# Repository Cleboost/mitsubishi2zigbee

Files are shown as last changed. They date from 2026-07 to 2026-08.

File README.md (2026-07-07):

# mitsubishi2zigbee

> [!CAUTION]
> **Early development — prototype only. Not production-ready.**
>
> This project is experimental and under active development. Firmware, wiring, and Zigbee behavior may change without notice. Bugs, incomplete features, and unexpected HVAC behavior are possible.
>
> **Do not rely on this device for critical climate control.** Use at your own risk. Test thoroughly before leaving it unattended.

Zigbee gateway firmware for Mitsubishi heat pumps and air conditioners with a **CN105** service port.

An **ESP32-C6** talks to the indoor unit over UART (CN105 protocol) and exposes it as a native Zigbee HVAC thermostat — no Wi-Fi or MQTT bridge on the microcontroller.

```
Home Assistant / Zigbee coordinator  ── Zigbee ──►  ESP32-C6  ── UART ──►  Mitsubishi unit
```

Inspired by [gysmo38/mitsubishi2MQTT](https://github.com/gysmo38/mitsubishi2MQTT), but uses Zigbee clusters (`hvacThermostat` + `hvacFanCtrl`) instead of MQTT.

## Features

| Category | Details |
| --- | --- |
| **Modes** | Off, Heat, Cool, Auto, Fan only, Dry |
| **Setpoint** | 16–31 °C in 0.5 °C steps |
| **Fan speed** | Auto, Quiet (Smart), Low, Medium, High |
| **Vane** | Auto, positions 1–5, Swing |
| **Telemetry** | Room temperature (unit sensor), compressor running state |
| **Status LED** (WS2812) | Fast blue — scanning · Slow blue — network found, not paired · Green pulse — paired |

## Hardware

### Supported board

- [Waveshare ESP32-C6-Zero](https://www.waveshare.com/esp32-c6-zero.htm) (or any ESP32-C6 dev board with similar pinout)
- Built with **ESP-IDF** via **PlatformIO**

### CN105 wiring

The CN105 port provides 12 V, 5 V, and 5 V logic UART lines.

| CN105 pin | Signal | ESP32-C6 | Notes |
| --- | --- | --- | --- |
| 1 | 12 V | — | Do **not** use to power the ESP |
| 2 | GND | GND | Common ground |
| 3 | 5 V | 5 V / VBUS | Powers the ESP32-C6 |
| 4 | TX (unit) | GPIO 5 (RX) | 5 V logic — use a level shifter (5 V → 3.3 V) |
| 5 | RX (unit) | GPIO 4 (TX) | 3.3 V from the ESP is sufficient |

> **Warning:** Never feed 12 V into the ESP. Power the board from the CN105 5 V pin only.

## Build and flash

### Prerequisites

- [PlatformIO](https://platformio.org/) (VS Code extension or CLI)

### Commands

```bash
cd firmware
pio run --target upload    # build and flash
pio device monitor         # serial logs (115200 baud)
```

## Zigbee pairing

1. Flash the firmware and power the board from the CN105 port.
2. Put your Zigbee coordinator into pairing mode.
3. Watch the status LED:
   - Fast blue — searching for a network
   - Slow blue — network found, waiting to join
   - Green pulse — joined successfully
4. The device advertises as **`MZ-Zigbee-C6`** (vendor: Mitsubishi).

## Zigbee2MQTT integration

> **To write** — step-by-step setup guide coming soon.

A video tutorial will cover the full Zigbee2MQTT setup (external converter, `configuration.yaml`, pairing, and Home Assistant entities). Stay tuned.

In the meantime, the external converter source is already available in [`zigbee2mqtt_converter/mitsubishi_esp32c6.js`](zigbee2mqtt_converter/mitsubishi_esp32c6.js).

## Project layout

```
mitsubishi2zigbee/
├── hardware/                  # KiCad PCB (CN105 carrier for ESP32-C6-Zero)
├── firmware/                  # ESP-IDF / PlatformIO project
│   └── src/
│       ├── main.cpp           # Zigbee endpoint + status LED
│       └── cn105.cpp          # Mitsubishi CN105 UART driver
└── zigbee2mqtt_converter/     # Optional Z2M external converter

```

## License

See repository license file.

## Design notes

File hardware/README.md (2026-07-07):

# Hardware

KiCad PCB for a [Waveshare ESP32-C6-Zero](https://www.waveshare.com/esp32-c6-zero.htm) carrier that plugs into a Mitsubishi **CN105** service port.

| Item | Details |
| --- | --- |
| MCU footprint | `Waveshare-ESP32:Waveshare-ESP32-C6-Zero_THT` (2×9 pin headers) |
| CN105 connector | `JST:JST_PA_B05B-PASK-1_1x05_P2.00mm_Vertical_CN105` |
| Level shifting | 5 V UART from the unit → 3.3 V for the ESP |

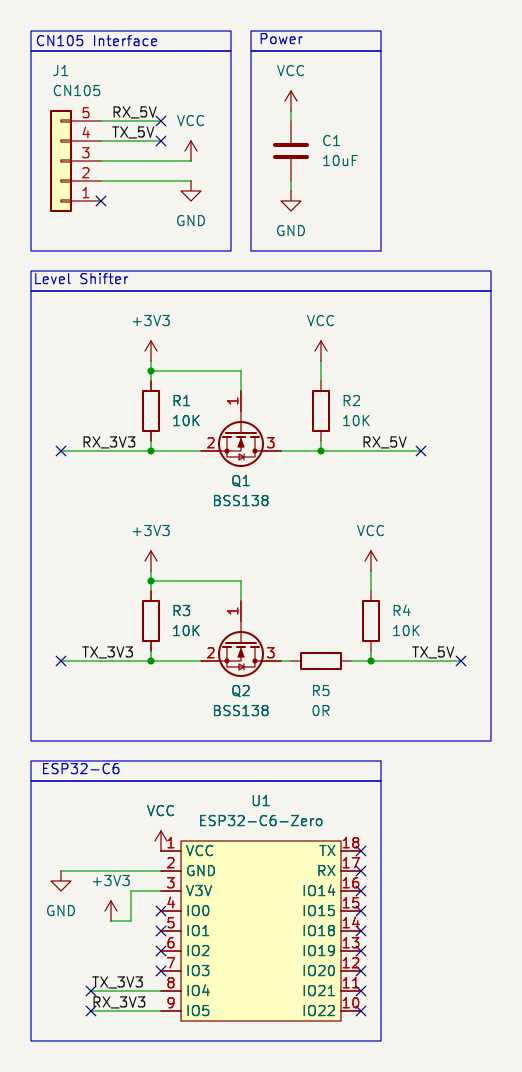
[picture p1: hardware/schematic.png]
Schematic


## Open in KiCad

```bash
kicad hardware/mitsubishi2zigbee.kicad_pro
```

Project-specific symbol and footprint libraries live in `libs/`.

## Layout

```
hardware/
├── README.md
├── schematic.png
├── mitsubishi2zigbee.kicad_pro
├── mitsubishi2zigbee.kicad_sch
├── mitsubishi2zigbee.kicad_pcb
├── fp-lib-table
├── sym-lib-table
└── libs/
    ├── JST.pretty/
    ├── Waveshare-ESP32.pretty/
    └── Waveshare-ESP32.kicad_sym
```

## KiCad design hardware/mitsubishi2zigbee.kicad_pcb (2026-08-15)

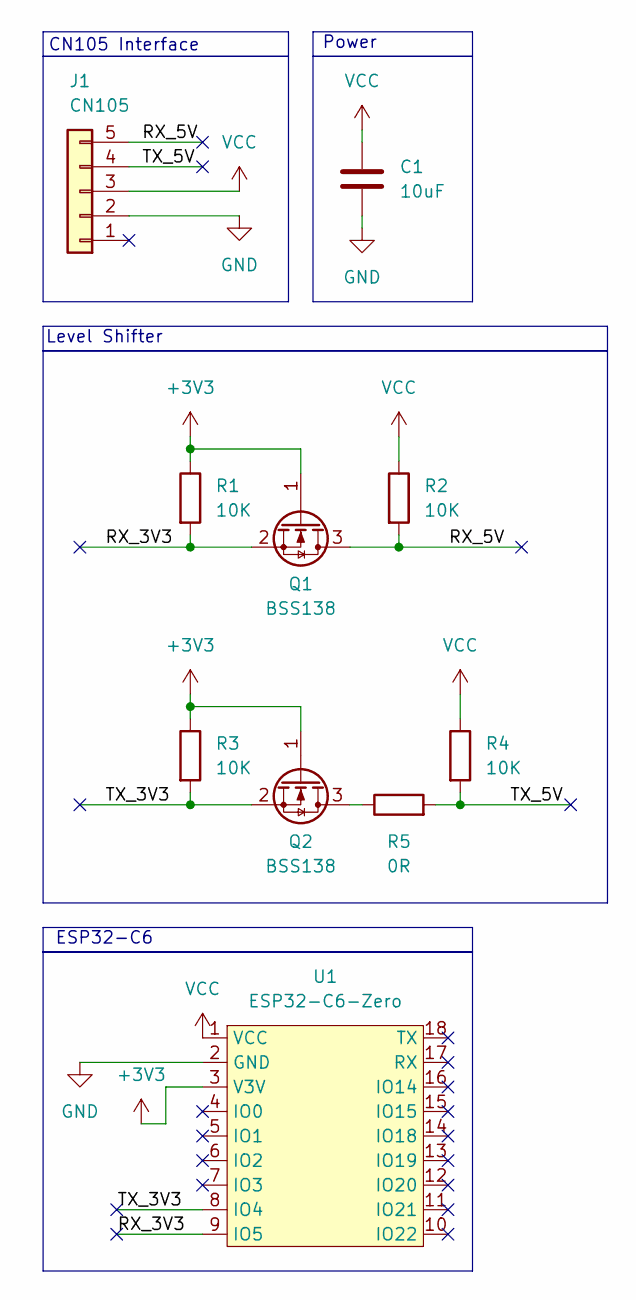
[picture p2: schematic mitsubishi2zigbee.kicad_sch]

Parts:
C1: 10uF; C_0805_2012Metric_Pad1.18x1.45mm_HandSolder
J1: CN105; JST_PA_B05B-PASK-1_1x05_P2.00mm_Vertical_CN105
Q1, Q2: BSS138; SOT-23
R1, R2, R3, R4: 10K; R_0805_2012Metric_Pad1.20x1.40mm_HandSolder
R5: 0R; R_1206_3216Metric_Pad1.30x1.75mm_HandSolder
U1: ESP32-C6-Zero; Waveshare-ESP32-C6-Zero_THT

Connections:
+3V3: Q1.1 (G), Q2.1 (G), R1.1, R3.1, U1.3 (V3V)
/RX_3V3: Q1.2 (S), R1.2, U1.9 (IO5)
/RX_5V: J1.5, Q1.3 (D), R2.2
/TX_3V3: Q2.2 (S), R3.2, U1.8 (IO4)
/TX_5V: J1.4, R4.2, R5.2
GND: C1.1, J1.2, U1.2 (GND)
unnamed: Q2.3 (D), R5.1
VCC: C1.2, J1.3, R2.1, R4.1, U1.1 (VCC)

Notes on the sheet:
CN105 Interface
Level Shifter
ESP32-C6
Power

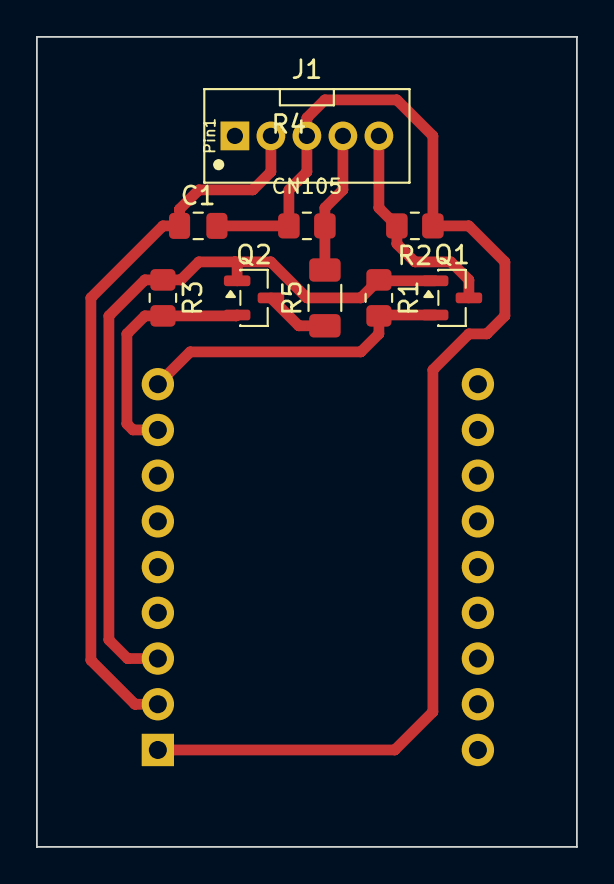
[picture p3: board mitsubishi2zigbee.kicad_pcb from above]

Board: 2 copper layers, 30.0 x 45.0 mm, 10 parts (1 on the bottom side), 8 nets.

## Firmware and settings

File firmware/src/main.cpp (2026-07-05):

// mitsubishi2zigbee — Zigbee gateway for Mitsubishi heat pumps (CN105)
//
// Based on gysmo38/mitsubishi2MQTT; exposes Thermostat + Fan Control clusters
// on ESP32-C6 (ESP-IDF) instead of MQTT.
//
//   Home Assistant ──Zigbee──► ESP32-C6 ──UART CN105──► Mitsubishi unit
//
// Status LED (WS2812, GPIO8): fast blue = scanning | slow blue = found, not paired | green = paired
#include "freertos/FreeRTOS.h"
#include "freertos/task.h"
#include "esp_check.h"
#include "esp_log.h"
#include "nvs_flash.h"
#include "led_strip.h"
#include "esp_zigbee_core.h"
#include "ha/esp_zigbee_ha_standard.h"
#include "bdb/esp_zigbee_bdb_commissioning.h"

#include "cn105.h"
#include "ota_zigbee.h"

static const char *TAG = "MITSU_ZB";

#define LED_PIN     8
#define LED_BRIGHT  20

typedef enum {
    LED_SEARCHING,
    LED_FOUND,
    LED_CONNECTED,
} led_state_t;

static volatile led_state_t g_led_state = LED_SEARCHING;
static led_strip_handle_t   g_led;

static void led_set(uint8_t r, uint8_t g, uint8_t b)
{
    led_strip_set_pixel(g_led, 0, r, g, b);
    led_strip_refresh(g_led);
}
static void led_off(void) { led_strip_clear(g_led); }

static void led_task(void *arg)
{
    led_strip_config_t strip_cfg = {};
    strip_cfg.strip_gpio_num = LED_PIN;
    strip_cfg.max_leds = 1;
    strip_cfg.led_model = LED_MODEL_WS2812;
    strip_cfg.color_component_format = LED_STRIP_COLOR_COMPONENT_FMT_RGB;

    led_strip_rmt_config_t rmt_cfg = {};
    rmt_cfg.resolution_hz = 10 * 1000 * 1000;
    ESP_ERROR_CHECK(led_strip_new_rmt_device(&strip_cfg, &rmt_cfg, &g_led));

    led_set(LED_BRIGHT, LED_BRIGHT, LED_BRIGHT);
    vTaskDelay(pdMS_TO_TICKS(1000));
    led_off();

    while (true) {
        switch (g_led_state) {
        case LED_SEARCHING:
            led_set(0, 0, LED_BRIGHT); vTaskDelay(pdMS_TO_TICKS(150));
            led_off();                 vTaskDelay(pdMS_TO_TICKS(150));
            break;
        case LED_FOUND:
            led_set(0, 0, LED_BRIGHT); vTaskDelay(pdMS_TO_TICKS(800));
            led_off();                 vTaskDelay(pdMS_TO_TICKS(800));
            break;
        case LED_CONNECTED:
            led_set(0, LED_BRIGHT, 0); vTaskDelay(pdMS_TO_TICKS(900));
            led_off();                 vTaskDelay(pdMS_TO_TICKS(100));
            break;
        }
    }
}

#define ENDPOINT_ID       1
#define CHANNEL_MASK      ESP_ZB_TRANSCEIVER_ALL_CHANNELS_MASK

#define MANUFACTURER_NAME "\x0A""Mitsubishi"
#define MODEL_ID          "\x0C""MZ-Zigbee-C6"

#define SETPOINT_DEFAULT  2100
#define SETPOINT_MIN      1600
#define SETPOINT_MAX      3100

#define VANE_ATTR_ID  0x0400

static hp_state_t g_hp = {};
static uint8_t    g_vane_attr = 0;

static void apply_system_mode(uint8_t sys_mode)
{
    switch (sys_mode) {
    case ESP_ZB_ZCL_THERMOSTAT_SYSTEM_MODE_OFF:
        cn105_set_power(false);
        break;
    case ESP_ZB_ZCL_THERMOSTAT_SYSTEM_MODE_HEAT:
        cn105_set_power(true); cn105_set_mode("HEAT");
        break;
    case ESP_ZB_ZCL_THERMOSTAT_SYSTEM_MODE_COOL:
        cn105_set_power(true); cn105_set_mode("COOL");
        break;
    case ESP_ZB_ZCL_THERMOSTAT_SYSTEM_MODE_AUTO:
        cn105_set_power(true); cn105_set_mode("AUTO");
        break;
    case ESP_ZB_ZCL_THERMOSTAT_SYSTEM_MODE_FAN_ONLY:
        cn105_set_power(true); cn105_set_mode("FAN");
        break;
    case ESP_ZB_ZCL_THERMOSTAT_SYSTEM_MODE_DRY:
        cn105_set_power(true); cn105_set_mode("DRY");
        break;
    default:
        ESP_LOGW(TAG, "unsupported system_mode 0x%02x", sys_mode);
        break;
    }
}

static const char *const VANE_NAMES[] = {"AUTO","1","2","3","4","5","SWING"};
#define VANE_COUNT 7

static void apply_vane(uint8_t idx)
{
    if (idx < VANE_COUNT) cn105_set_vane(VANE_NAMES[idx]);
}

static uint8_t hp_to_vane_idx(const hp_state_t *st)
{
    for (int i = 0; i < VANE_COUNT; i++)
        if (strcmp(st->vane, VANE_NAMES[i]) == 0) return (uint8_t)i;
    return 0;
}

static void apply_fan_mode(uint8_t fan_mode)
{
    switch (fan_mode) {
    case ESP_ZB_ZCL_FAN_CONTROL_FAN_MODE_LOW:    cn105_set_fan("1");     break;
    case ESP_ZB_ZCL_FAN_CONTROL_FAN_MODE_MEDIUM: cn105_set_fan("2");     break;
    case ESP_ZB_ZCL_FAN_CONTROL_FAN_MODE_HIGH:   cn105_set_fan("4");     break;
    case ESP_ZB_ZCL_FAN_CONTROL_FAN_MODE_ON:     cn105_set_fan("4");     break;
    case ESP_ZB_ZCL_FAN_CONTROL_FAN_MODE_SMART:  cn105_set_fan("QUIET"); break;
    case ESP_ZB_ZCL_FAN_CONTROL_FAN_MODE_AUTO:
    default:                                     cn105_set_fan("AUTO");  break;
    }
}

static uint8_t hp_to_system_mode(const hp_state_t *st)
{
    if (!st->power_on)               return ESP_ZB_ZCL_THERMOSTAT_SYSTEM_MODE_OFF;
    if (strcmp(st->mode, "HEAT")==0) return ESP_ZB_ZCL_THERMOSTAT_SYSTEM_MODE_HEAT;
    if (strcmp(st->mode, "COOL")==0) return ESP_ZB_ZCL_THERMOSTAT_SYSTEM_MODE_COOL;
    if (strcmp(st->mode, "DRY")==0)  return ESP_ZB_ZCL_THERMOSTAT_SYSTEM_MODE_DRY;
    if (strcmp(st->mode, "FAN")==0)  return ESP_ZB_ZCL_THERMOSTAT_SYSTEM_MODE_FAN_ONLY;
    return ESP_ZB_ZCL_THERMOSTAT_SYSTEM_MODE_AUTO;
}

static uint8_t hp_to_fan_mode(const hp_state_t *st)
{
    if (strcmp(st->fan, "QUIET")==0) return ESP_ZB_ZCL_FAN_CONTROL_FAN_MODE_SMART;
    if (strcmp(st->fan, "1")==0)     return ESP_ZB_ZCL_FAN_CONTROL_FAN_MODE_LOW;
    if (strcmp(st->fan, "2")==0)     return ESP_ZB_ZCL_FAN_CONTROL_FAN_MODE_MEDIUM;
    if (strcmp(st->fan, "3")==0)     return ESP_ZB_ZCL_FAN_CONTROL_FAN_MODE_HIGH;
    if (strcmp(st->fan, "4")==0)     return ESP_ZB_ZCL_FAN_CONTROL_FAN_MODE_HIGH;
    return ESP_ZB_ZCL_FAN_CONTROL_FAN_MODE_AUTO;
}

static void push_state_to_zigbee(const hp_state_t *st)
{
    int16_t local_temp = (int16_t)(st->room_temp * 100.0f);
    int16_t setpoint   = (int16_t)(st->target_temp * 100.0f);
    uint8_t sys_mode   = hp_to_system_mode(st);
    uint8_t fan_mode   = hp_to_fan_mode(st);

    esp_zb_lock_acquire(portMAX_DELAY);
    esp_zb_zcl_set_attribute_val(ENDPOINT_ID,
        ESP_ZB_ZCL_CLUSTER_ID_THERMOSTAT, ESP_ZB_ZCL_CLUSTER_SERVER_ROLE,
        ESP_ZB_ZCL_ATTR_THERMOSTAT_LOCAL_TEMPERATURE_ID, &local_temp, false);
    esp_zb_zcl_set_attribute_val(ENDPOINT_ID,
        ESP_ZB_ZCL_CLUSTER_ID_THERMOSTAT, ESP_ZB_ZCL_CLUSTER_SERVER_ROLE,
        ESP_ZB_ZCL_ATTR_THERMOSTAT_OCCUPIED_HEATING_SETPOINT_ID, &setpoint, false);
    esp_zb_zcl_set_attribute_val(ENDPOINT_ID,
        ESP_ZB_ZCL_CLUSTER_ID_THERMOSTAT, ESP_ZB_ZCL_CLUSTER_SERVER_ROLE,
        ESP_ZB_ZCL_ATTR_THERMOSTAT_OCCUPIED_COOLING_SETPOINT_ID, &setpoint, false);
    esp_zb_zcl_set_attribute_val(ENDPOINT_ID,
        ESP_ZB_ZCL_CLUSTER_ID_THERMOSTAT, ESP_ZB_ZCL_CLUSTER_SERVER_ROLE,
        ESP_ZB_ZCL_ATTR_THERMOSTAT_SYSTEM_MODE_ID, &sys_mode, false);
    esp_zb_zcl_set_attribute_val(ENDPOINT_ID,
        ESP_ZB_ZCL_CLUSTER_ID_FAN_CONTROL, ESP_ZB_ZCL_CLUSTER_SERVER_ROLE,
        ESP_ZB_ZCL_ATTR_FAN_CONTROL_FAN_MODE_ID, &fan_mode, false);
    g_vane_attr = hp_to_vane_idx(st);
    esp_zb_zcl_set_attribute_val(ENDPOINT_ID,
        ESP_ZB_ZCL_CLUSTER_ID_THERMOSTAT, ESP_ZB_ZCL_CLUSTER_SERVER_ROLE,
        VANE_ATTR_ID, &g_vane_attr, false);
    esp_zb_lock_release();
}

static esp_err_t zb_action_handler(esp_zb_core_action_callback_id_t callback_id,
                                   const void *message)
{
    if (callback_id == ESP_ZB_CORE_OTA_UPGRADE_VALUE_CB_ID ||
        callback_id == ESP_ZB_CORE_OTA_UPGRADE_QUERY_IMAGE_RESP_CB_ID) {
        return ota_zigbee_action_handler(callback_id, message);
    }
    if (callback_id != ESP_ZB_CORE_SET_ATTR_VALUE_CB_ID) return ESP_OK;

    const esp_zb_zcl_set_attr_value_message_t *m =
        (const esp_zb_zcl_set_attr_value_message_t *)message;
    if (m->info.status != ESP_ZB_ZCL_STATUS_SUCCESS) return ESP_OK;

    uint16_t cluster = m->info.cluster;
    uint16_t attr    = m->attribute.id;
    void    *val     = m->attribute.data.value;

    if (cluster == ESP_ZB_ZCL_CLUSTER_ID_THERMOSTAT) {
        if (attr == ESP_ZB_ZCL_ATTR_THERMOSTAT_SYSTEM_MODE_ID) {
            apply_system_mode(*(uint8_t *)val);
        } else if (attr == ESP_ZB_ZCL_ATTR_THERMOSTAT_OCCUPIED_HEATING_SETPOINT_ID ||
                   attr == ESP_ZB_ZCL_ATTR_THERMOSTAT_OCCUPIED_COOLING_SETPOINT_ID) {
            int16_t centi = *(int16_t *)val;
            cn105_set_temp(centi / 100.0f);
        } else if (attr == VANE_ATTR_ID) {
            apply_vane(*(uint8_t *)val);
        }
    } else if (cluster == ESP_ZB_ZCL_CLUSTER_ID_FAN_CONTROL) {
        if (attr == ESP_ZB_ZCL_ATTR_FAN_CONTROL_FAN_MODE_ID) {
            apply_fan_mode(*(uint8_t *)val);
        }
    }
    return ESP_OK;
}

static void bdb_start_commissioning_cb(uint8_t mode_mask)
{
    ESP_RETURN_ON_FALSE(
        esp_zb_bdb_start_top_level_commissioning(mode_mask) == ESP_OK,
        , TAG, "commissioning start failed");
}

extern "C" void esp_zb_app_signal_handler(esp_zb_app_signal_t *signal_struct)
{
    uint32_t *p_sg_p     = signal_struct->p_app_signal;
    esp_err_t err_status = signal_struct->esp_err_status;
    esp_zb_app_signal_type_t sig_type = (esp_zb_app_signal_type_t)*p_sg_p;

    switch (sig_type) {
    case ESP_ZB_ZDO_SIGNAL_SKIP_STARTUP:
        esp_zb_bdb_start_top_level_commissioning(ESP_ZB_BDB_MODE_INITIALIZATION);
        break;

    case ESP_ZB_BDB_SIGNAL_DEVICE_FIRST_START:
    case ESP_ZB_BDB_SIGNAL_DEVICE_REBOOT:
        if (err_status == ESP_OK) {
            g_led_state = LED_SEARCHING;
            esp_zb_bdb_start_top_level_commissioning(ESP_ZB_BDB_MODE_NETWORK_STEERING);
        } else {
            ESP_LOGW(TAG, "stack init failed: %s", esp_err_to_name(err_status));
        }
        break;

    case ESP_ZB_BDB_SIGNAL_STEERING: {
        uint16_t addr = esp_zb_get_short_address();
        bool in_network = (addr != 0xFFFE && addr != 0xFFFF);
        if (in_network) {
            g_led_state = LED_CONNECTED;
            ESP_LOGI(TAG, "paired — PAN=0x%04hx channel=%d addr=0x%04hx",
                     esp_zb_get_pan_id(), esp_zb_get_current_channel(), addr);
            esp_zb_bdb_finding_binding_start_target(ENDPOINT_ID, 300);
        } else {
            g_led_state = LED_FOUND;
            esp_zb_scheduler_alarm((esp_zb_callback_t)bdb_start_commissioning_cb,
                                   ESP_ZB_BDB_MODE_NETWORK_STEERING, 1000);
        }
        break;
    }

    case ESP_ZB_NWK_SIGNAL_PERMIT_JOIN_STATUS:
        g_led_state = LED_CONNECTED;
        break;

    default:
        ESP_LOGI(TAG, "ZDO signal: %s (0x%x), status: %s",
                 esp_zb_zdo_signal_to_string(sig_type), sig_type,
                 esp_err_to_name(err_status));
        break;
    }
}

static esp_zb_cluster_list_t *create_hvac_cluster_list(void)
{
    esp_zb_cluster_list_t *list = esp_zb_zcl_cluster_list_create();

    esp_zb_basic_cluster_cfg_t basic_cfg = {
        .zcl_version  = ESP_ZB_ZCL_BASIC_ZCL_VERSION_DEFAULT_VALUE,
        .power_source = 0x01,
    };
    esp_zb_attribute_list_t *basic = esp_zb_basic_cluster_create(&basic_cfg);
    esp_zb_basic_cluster_add_attr(basic,
        ESP_ZB_ZCL_ATTR_BASIC_MANUFACTURER_NAME_ID, (void *)MANUFACTURER_NAME);
    esp_zb_basic_cluster_add_attr(basic,
        ESP_ZB_ZCL_ATTR_BASIC_MODEL_IDENTIFIER_ID, (void *)MODEL_ID);
    esp_zb_basic_cluster_add_attr(basic,
        ESP_ZB_ZCL_ATTR_BASIC_SW_BUILD_ID, (void *)FW_VERSION_STRING);
    esp_zb_cluster_list_add_basic_cluster(list, basic, ESP_ZB_ZCL_CLUSTER_SERVER_ROLE);

    esp_zb_identify_cluster_cfg_t id_cfg = { .identify_time = 0 };
    esp_zb_cluster_list_add_identify_cluster(list,
        esp_zb_identify_cluster_create(&id_cfg), ESP_ZB_ZCL_CLUSTER_SERVER_ROLE);

    esp_zb_thermostat_cluster_cfg_t th_cfg = {
        .local_temperature             = 2100,
        .occupied_cooling_setpoint     = SETPOINT_DEFAULT,
        .occupied_heating_setpoint     = SETPOINT_DEFAULT,
        .control_sequence_of_operation =
            ESP_ZB_ZCL_THERMOSTAT_CONTROL_SEQ_OF_OPERATION_COOLING_AND_HEATING_4_PIPES,
        .system_mode                   = ESP_ZB_ZCL_THERMOSTAT_SYSTEM_MODE_OFF,
    };
    esp_zb_attribute_list_t *th = esp_zb_thermostat_cluster_create(&th_cfg);
    int16_t lim_min = SETPOINT_MIN, lim_max = SETPOINT_MAX;
    esp_zb_thermostat_cluster_add_attr(th,
        ESP_ZB_ZCL_ATTR_THERMOSTAT_MIN_HEAT_SETPOINT_LIMIT_ID, &lim_min);
    esp_zb_thermostat_cluster_add_attr(th,
        ESP_ZB_ZCL_ATTR_THERMOSTAT_MAX_HEAT_SETPOINT_LIMIT_ID, &lim_max);
    esp_zb_thermostat_cluster_add_attr(th,
        ESP_ZB_ZCL_ATTR_THERMOSTAT_MIN_COOL_SETPOINT_LIMIT_ID, &lim_min);
    esp_zb_thermostat_cluster_add_attr(th,
        ESP_ZB_ZCL_ATTR_THERMOSTAT_MAX_COOL_SETPOINT_LIMIT_ID, &lim_max);
    esp_zb_thermostat_cluster_add_attr(th, VANE_ATTR_ID, &g_vane_attr);
    esp_zb_cluster_list_add_thermostat_cluster(list, th, ESP_ZB_ZCL_CLUSTER_SERVER_ROLE);

    esp_zb_fan_control_cluster_cfg_t fan_cfg = {
        .fan_mode          = ESP_ZB_ZCL_FAN_CONTROL_FAN_MODE_AUTO,
        .fan_mode_sequence = ESP_ZB_ZCL_FAN_CONTROL_FAN_MODE_SEQUENCE_LOW_MED_HIGH_AUTO,
    };
    esp_zb_cluster_list_add_fan_control_cluster(list,
        esp_zb_fan_control_cluster_create(&fan_cfg), ESP_ZB_ZCL_CLUSTER_SERVER_ROLE);

    return list;
}

static void hp_sync_task(void *arg)
{
    cn105_init();

    while (!g_hp.connected) {
        cn105_connect();
        for (int i = 0; i < 10 && !g_hp.connected; i++) {
            vTaskDelay(pdMS_TO_TICKS(100));
            cn105_poll(&g_hp);
        }
        if (!g_hp.connected) ESP_LOGW(TAG, "no response from unit, retrying...");
    }
    ESP_LOGI(TAG, "Mitsubishi unit connected");

    uint8_t cycle = 0;
    while (true) {
        switch (cycle % 3) {
        case 0: cn105_request_settings();  break;
        case 1: cn105_request_room_temp(); break;
        case 2: cn105_request_status();    break;
        }
        cycle++;

        bool changed = false;
        for (int i = 0; i < 10; i++) {
            vTaskDelay(pdMS_TO_TICKS(100));
            if (cn105_poll(&g_hp)) changed = true;
        }

        if (changed) {
            push_state_to_zigbee(&g_hp);
            ESP_LOGI(TAG, "state: %s %s | setpoint %.1f°C | room %.1f°C | fan %s | %s",
                     g_hp.power_on ? "ON" : "OFF", g_hp.mode,
                     g_hp.target_temp, g_hp.room_temp, g_hp.fan,
                     g_hp.operating ? "running" : "idle");
        }
    }
}

static void esp_zb_task(void *pvParameters)
{
    esp_zb_aps_src_binding_table_size_set(32);
    esp_zb_aps_dst_binding_table_size_set(32);

    esp_zb_cfg_t zb_nwk_cfg = {};
    zb_nwk_cfg.esp_zb_role = ESP_ZB_DEVICE_TYPE_ROUTER;
    zb_nwk_cfg.install_code_policy = false;
    zb_nwk_cfg.nwk_cfg.zczr_cfg.max_children = 10;
    esp_zb_init(&zb_nwk_cfg);

    esp_zb_ep_list_t *ep_list = esp_zb_ep_list_create();
    esp_zb_endpoint_config_t ep_cfg = {
        .endpoint           = ENDPOINT_ID,
        .app_profile_id     = ESP_ZB_AF_HA_PROFILE_ID,
        .app_device_id      = ESP_ZB_HA_THERMOSTAT_DEVICE_ID,
        .app_device_version = 0,
    };
    esp_zb_ep_list_add_ep(ep_list, create_hvac_cluster_list(), ep_cfg);
    ESP_ERROR_CHECK(ota_zigbee_register_endpoint(ep_list));
    esp_zb_device_register(ep_list);

    esp_zb_core_action_handler_register(zb_action_handler);

    esp_zb_set_primary_network_channel_set(CHANNEL_MASK);
    esp_zb_secur_network_min_join_lqi_set(0);

    ESP_ERROR_CHECK(esp_zb_start(false));
    esp_zb_stack_main_loop();
}

extern "C" void app_main(void)
{
    ESP_ERROR_CHECK(nvs_flash_init());

    esp_zb_platform_config_t config = {};
    config.radio_config.radio_mode = ZB_RADIO_MODE_NATIVE;
    config.host_config.host_connection_mode = ZB_HOST_CONNECTION_MODE_NONE;
    ESP_ERROR_CHECK(esp_zb_platform_config(&config));

    ESP_LOGI(TAG, "=== mitsubishi2zigbee — CN105 ↔ Zigbee gateway ===");
    ESP_LOGI(TAG, "firmware OTA version 0x%08lx (manuf 0x%04x type 0x%04x)",
             (unsigned long)OTA_FILE_VERSION, OTA_MANUFACTURER_CODE, OTA_IMAGE_TYPE);

    xTaskCreate(led_task,     "led",     4096, NULL, 3, NULL);
    xTaskCreate(hp_sync_task, "hp_sync", 4096, NULL, 4, NULL);
    xTaskCreate(esp_zb_task,  "esp_zb",  4096, NULL, 5, NULL);
}

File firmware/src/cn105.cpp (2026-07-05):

// cn105.cpp — Mitsubishi CN105 protocol (ESP-IDF)
// Protocol constants from SwiCago/HeatPump (LGPL).
#include "cn105.h"

#include <string.h>
#include <math.h>
#include "esp_log.h"
#include "freertos/FreeRTOS.h"
#include "freertos/task.h"

static const char *TAG = "CN105";

#define PACKET_LEN  22
#define RX_BUF_SIZE 256

static const uint8_t CONNECT[]    = {0xfc, 0x5a, 0x01, 0x30, 0x02, 0xca, 0x01, 0xa8};
static const uint8_t INFOHEADER[] = {0xfc, 0x42, 0x01, 0x30, 0x10};
static const uint8_t SETHEADER[]  = {0xfc, 0x41, 0x01, 0x30, 0x10};

#define TYPE_INFO_RESP    0x62
#define TYPE_SET_ACK      0x61
#define TYPE_CONNECT_ACK  0x7a

#define INFO_SETTINGS     0x02
#define INFO_ROOM_TEMP    0x03
#define INFO_STATUS       0x06

#define CTRL_POWER  0x01
#define CTRL_MODE   0x02
#define CTRL_TEMP   0x04
#define CTRL_FAN    0x08
#define CTRL_VANE   0x10

static const uint8_t     POWER_B[]  = {0x00, 0x01};
static const char *const POWER_S[]  = {"OFF", "ON"};
static const uint8_t     MODE_B[]   = {0x01, 0x02, 0x03, 0x07, 0x08};
static const char *const MODE_S[]   = {"HEAT", "DRY", "COOL", "FAN", "AUTO"};
static const uint8_t     FAN_B[]    = {0x00, 0x01, 0x02, 0x03, 0x05, 0x06};
static const char *const FAN_S[]    = {"AUTO", "QUIET", "1", "2", "3", "4"};
static const uint8_t     VANE_B[]   = {0x00, 0x01, 0x02, 0x03, 0x04, 0x05, 0x07};
static const char *const VANE_S[]   = {"AUTO", "1", "2", "3", "4", "5", "SWING"};

static const char *byte_to_str(uint8_t b, const uint8_t *bytes, const char *const *strs, int n)
{
    for (int i = 0; i < n; i++) if (bytes[i] == b) return strs[i];
    return strs[0];
}

static uint8_t str_to_byte(const char *s, const uint8_t *bytes, const char *const *strs, int n)
{
    for (int i = 0; i < n; i++) if (strcmp(strs[i], s) == 0) return bytes[i];
    return bytes[0];
}

static uint8_t checksum(const uint8_t *p, int len)
{
    uint8_t sum = 0;
    for (int i = 0; i < len; i++) sum += p[i];
    return (0xfc - sum) & 0xff;
}

static void write_packet(uint8_t *packet)
{
    packet[PACKET_LEN - 1] = checksum(packet, PACKET_LEN - 1);
    uart_write_bytes(CN105_UART_PORT, (const char *)packet, PACKET_LEN);
}

void cn105_init(void)
{
    uart_config_t cfg = {};
    cfg.baud_rate  = 2400;
    cfg.data_bits  = UART_DATA_8_BITS;
    cfg.parity     = UART_PARITY_EVEN;          // 8E1
    cfg.stop_bits  = UART_STOP_BITS_1;
    cfg.flow_ctrl  = UART_HW_FLOWCTRL_DISABLE;
    cfg.source_clk = UART_SCLK_DEFAULT;

    ESP_ERROR_CHECK(uart_driver_install(CN105_UART_PORT, RX_BUF_SIZE * 2, 0, 0, NULL, 0));
    ESP_ERROR_CHECK(uart_param_config(CN105_UART_PORT, &cfg));
    ESP_ERROR_CHECK(uart_set_pin(CN105_UART_PORT, CN105_TX_PIN, CN105_RX_PIN,
                                 UART_PIN_NO_CHANGE, UART_PIN_NO_CHANGE));
    ESP_LOGI(TAG, "UART%d ready (2400 8E1, TX=%d RX=%d)",
             CN105_UART_PORT, CN105_TX_PIN, CN105_RX_PIN);
}

void cn105_connect(void)
{
    uart_write_bytes(CN105_UART_PORT, (const char *)CONNECT, sizeof(CONNECT));
    ESP_LOGI(TAG, "→ CONNECT");
}

static void request_info(uint8_t info_mode)
{
    uint8_t packet[PACKET_LEN] = {};
    memcpy(packet, INFOHEADER, sizeof(INFOHEADER));
    packet[5] = info_mode;
    write_packet(packet);
}

void cn105_request_settings(void)  { request_info(INFO_SETTINGS); }
void cn105_request_room_temp(void) { request_info(INFO_ROOM_TEMP); }
void cn105_request_status(void)    { request_info(INFO_STATUS); }

static void send_set(uint8_t control, uint8_t power, uint8_t mode,
                     float temp, uint8_t fan)
{
    uint8_t packet[PACKET_LEN] = {};
    memcpy(packet, SETHEADER, sizeof(SETHEADER));
    packet[5] = 0x01;
    packet[6] = control;
    packet[7] = 0x00;       // wideVane unused

    if (control & CTRL_POWER) packet[8]  = power;
    if (control & CTRL_MODE)  packet[9]  = mode;
    if (control & CTRL_TEMP) {
        // Legacy encoding: 31 - integer temp at byte 10
        int t = (int)lroundf(temp);
        if (t < 16) t = 16;
        if (t > 31) t = 31;
        packet[10] = 31 - t;
        // 0.5°C encoding: (temp*2)+128 at byte 19 (newer units)
        packet[19] = (uint8_t)((int)lroundf(temp * 2.0f) + 128);
    }
    if (control & CTRL_FAN)  packet[11] = fan;

    write_packet(packet);
}

void cn105_set_power(bool on)
{
    send_set(CTRL_POWER, on ? 0x01 : 0x00, 0, 0, 0);
    ESP_LOGI(TAG, "→ SET power=%s", on ? "ON" : "OFF");
}

void cn105_set_mode(const char *mode)
{
    uint8_t b = str_to_byte(mode, MODE_B, MODE_S, 5);
    send_set(CTRL_MODE, 0, b, 0, 0);
    ESP_LOGI(TAG, "→ SET mode=%s", mode);
}

void cn105_set_temp(float temp_c)
{
    if (temp_c < 16.0f) temp_c = 16.0f;
    if (temp_c > 31.0f) temp_c = 31.0f;
    temp_c = roundf(temp_c * 2.0f) / 2.0f;
    send_set(CTRL_TEMP, 0, 0, temp_c, 0);
    ESP_LOGI(TAG, "→ SET temp=%.1f", temp_c);
}

void cn105_set_fan(const char *fan)
{
    uint8_t b = str_to_byte(fan, FAN_B, FAN_S, 6);
    send_set(CTRL_FAN, 0, 0, 0, b);
    ESP_LOGI(TAG, "→ SET fan=%s", fan);
}

void cn105_set_vane(const char *vane)
{
    uint8_t b = str_to_byte(vane, VANE_B, VANE_S, 7);
    uint8_t packet[PACKET_LEN] = {};
    memcpy(packet, SETHEADER, sizeof(SETHEADER));
    packet[5] = 0x01;
    packet[6] = CTRL_VANE;
    packet[12] = b;
    write_packet(packet);
    ESP_LOGI(TAG, "→ SET vane=%s", vane);
}

static bool parse_info(const uint8_t *data, int dlen, hp_state_t *st)
{
    bool changed = false;
    uint8_t info_mode = data[0];

    if (info_mode == INFO_SETTINGS && dlen >= 12) {
        bool power = (data[3] == 0x01);
        if (power != st->power_on) { st->power_on = power; changed = true; }

        const char *mode = byte_to_str(data[4] & 0x07, MODE_B, MODE_S, 5);
        if (strcmp(mode, st->mode) != 0) { strncpy(st->mode, mode, sizeof(st->mode)); changed = true; }

        float temp;
        if (data[11] != 0x00) temp = (data[11] - 128) / 2.0f;   // 0.5°C mode
        else                  temp = 31.0f - data[5];           // legacy mode
        if (fabsf(temp - st->target_temp) > 0.01f) { st->target_temp = temp; changed = true; }

        const char *fan = byte_to_str(data[6], FAN_B, FAN_S, 6);
        if (strcmp(fan, st->fan) != 0) { strncpy(st->fan, fan, sizeof(st->fan)); changed = true; }

        const char *vane = byte_to_str(data[7], VANE_B, VANE_S, 7);
        if (strcmp(vane, st->vane) != 0) { strncpy(st->vane, vane, sizeof(st->vane)); changed = true; }
    }
    else if (info_mode == INFO_ROOM_TEMP && dlen >= 7) {
        float temp;
        if (data[6] != 0x00) temp = (data[6] - 128) / 2.0f;     // 0.5°C mode
        else                 temp = 10.0f + data[3];            // legacy mode
        if (fabsf(temp - st->room_temp) > 0.01f) { st->room_temp = temp; changed = true; }
    }
    else if (info_mode == INFO_STATUS && dlen >= 5) {
        bool op = (data[4] != 0x00);
        if (op != st->operating) { st->operating = op; changed = true; }
    }
    return changed;
}
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

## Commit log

2026-07-05 Initial commit: Zigbee CN105 gateway firmware and docs.
    ESP32-C6 firmware bridges Mitsubishi HVAC units over CN105 to Zigbee, with README and Zigbee2MQTT converter stub.
    [partitions.csv]
2026-07-05 Add Zigbee OTA support for zigbee2mqtt updates.
    Dual OTA partitions on 4MB flash, dedicated OTA endpoint, firmware version
    exposure, and a resilient Z2M converter with OTA index and build script.
    [partitions.csv]
2026-07-07 Add KiCad hardware design for CN105 carrier board.
    [mitsubishi2zigbee.kicad_pcb, mitsubishi2zigbee.kicad_sch]
2026-07-07 Update KiCad hardware schematic layout and component labels.
    Reorganize schematic into functional sections and rename CN105/ESP32-C6 values for clarity.
    [mitsubishi2zigbee.kicad_pcb, mitsubishi2zigbee.kicad_sch]
2026-07-07 Add cropped schematic preview image to hardware docs.
    Include schematic.png in the hardware README for quick visual reference.
2026-08-15 Feat(pcb): add gr_rect element
    [mitsubishi2zigbee.kicad_pcb]
2026-08-15 refactor(kicad-pcb): tweak plot configuration and output directory
    - update layerselection and plot_on_all_layers_selection masks
    - adjust PDF metadata and popup settings
    - modify outputdirectory to target location
    - change drillshape, mirror, and outputformat values
    - relocate drawing element to Edge.Cuts layer with new UUID
    [mitsubishi2zigbee.kicad_pcb]
2026-10-27 fix(firmware): swap CN105 TX and RX pins to match PCB routing
2026-10-27 fix(pcb): correct U1 pitch to 15.24mm and adapt pads for DIY etching/drilling
    - Correct ESP32-C6-Zero footprint pitch from 17.78mm to official 15.24mm
    - Reroute VCC trace around pin headers to ensure proper clearance
    - Enlarge U1 pads to 2.1mm (0.9mm drill) for manual Dremel drilling
    - Enlarge J1 pads to 1.5x2.2mm oval (0.8mm drill) and add 1.1mm boss hole
    - Maintain 100% single-face F.Cu routing with 0 DRC/ERC errors
2026-10-27 feat(hardware): add ready-to-print DIY etching typon with alignment marks and Cu text
2026-10-27 fix(typon): offset cutting frame and crosshairs by 5mm around PCB for transparent paper trimming
2026-10-27 fix(typon): align cutting frame and alignment crosses exactly with final PCB dimensions (30x45mm)
2026-10-27 feat(nix): add shell.nix with PlatformIO, KiCad, esptool, and Node.js
2026-10-27 feat: add Justfile for common dev tasks (build, upload, monitor, typon, check-pcb)
2026-10-27 fix(hardware): adapt THT pads for 0.8mm drill and regenerate etching typons
    - Enlarge ESP32-C6-Zero pads to 2.1mm with 0.8mm drill for 0.65mm annular copper ring
    - Maintain 0.8mm drill on CN105 oval pads (1.5x2.2mm)
    - Update footprint library Waveshare-ESP32-C6-Zero_THT and PCB file
    - Regenerate etching typons (typon_echelle1_A4.pdf and typon_echelle1_carte.svg)
2026-10-27 fix(pcb): increase clearance between left-side parallel tracks to 0.9mm
    - Shift GND track outward to x=113.6mm and /TX_3V3 inward to x=116.4mm
    - Set track widths to 0.5mm on the parallel bus (+3V3, GND, /TX_3V3)
    - Expand inter-track clearance from 0.4mm to 0.9mm (well above the 0.4mm etching minimum)
    - Maintain strict 45-degree routing and 0 DRC/connectivity errors
    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
2026-10-30 feat: Zigbee HVAC gateway with vane control and CN105 integration
    Firmware and Z2M converter for full climate control (modes, setpoint, fan,
    vane via cluster 0xFF00), corrected CN105 UART pins, and stripped debug/dead code.
2026-11-09 refactor(firmware): centralize Zigbee manifest and defer CN105 flush
    Move device constants to device_manifest.h; CN105 setters only update
    wanted state and hp_sync_task owns UART poll/flush.
